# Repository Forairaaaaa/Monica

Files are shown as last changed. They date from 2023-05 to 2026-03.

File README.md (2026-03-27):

# Monica

视频介绍：https://www.bilibili.com/video/BV1AP411Q7dk

硬件开源：https://oshwhub.com/eda_rgprdhwej/monica

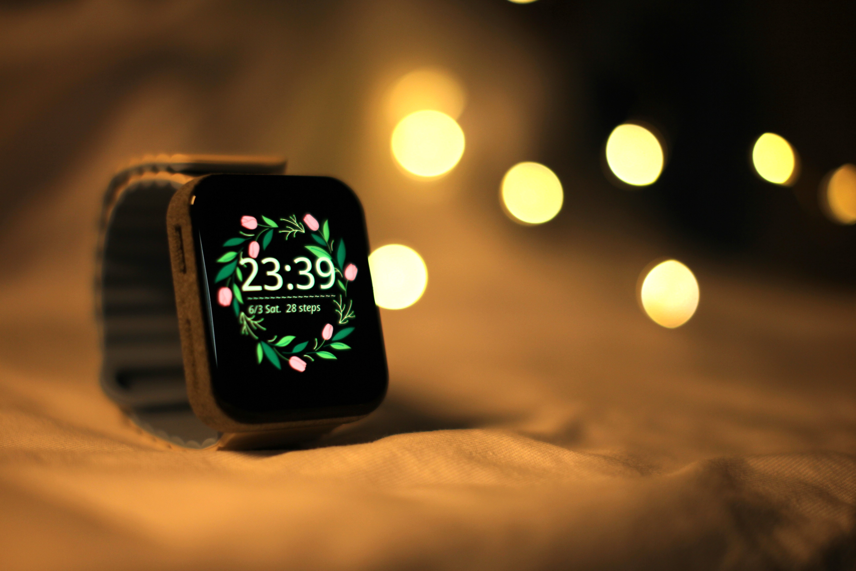
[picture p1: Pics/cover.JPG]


### 原理图

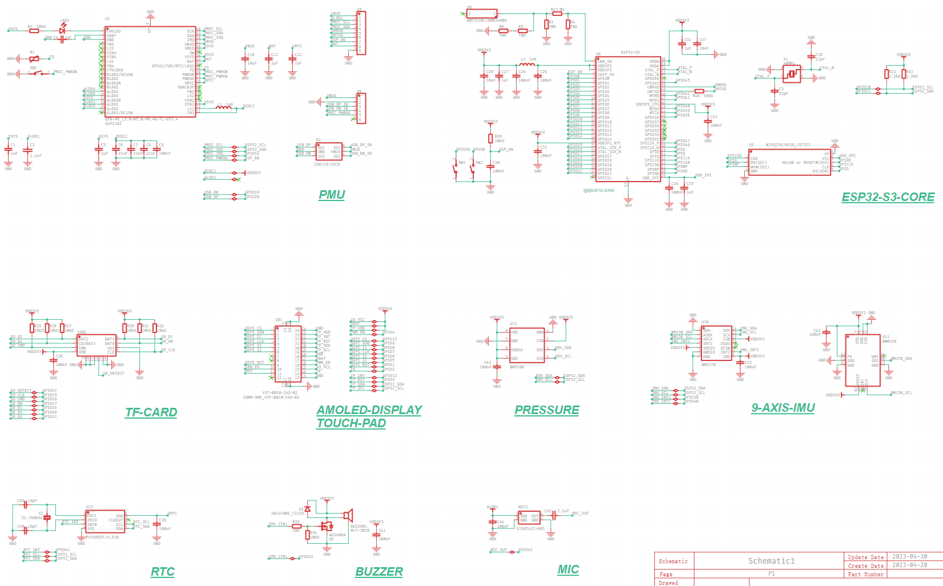
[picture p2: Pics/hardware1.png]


- **主控**：ESP32-S3，32M 外置 Flash
- **IMU**：BMI270 + BM150 （抬手唤醒、计步器、指南针）
- **电源管理**：AXP2101
- **其他**：SD卡槽、RTC、蜂鸣器、MIC、气压传感、按键
- [**屏幕**](https://item.taobao.com/item.htm?spm=a1z09.2.0.0.a41c2e8dNZ5GOq&id=688638221390)：1.8寸 Amoled 368*448 
- **[电池](https://detail.tmall.com/item.htm?_u=42bdtj0f19f8&id=632947661144)**：402728 400毫安

### PCB

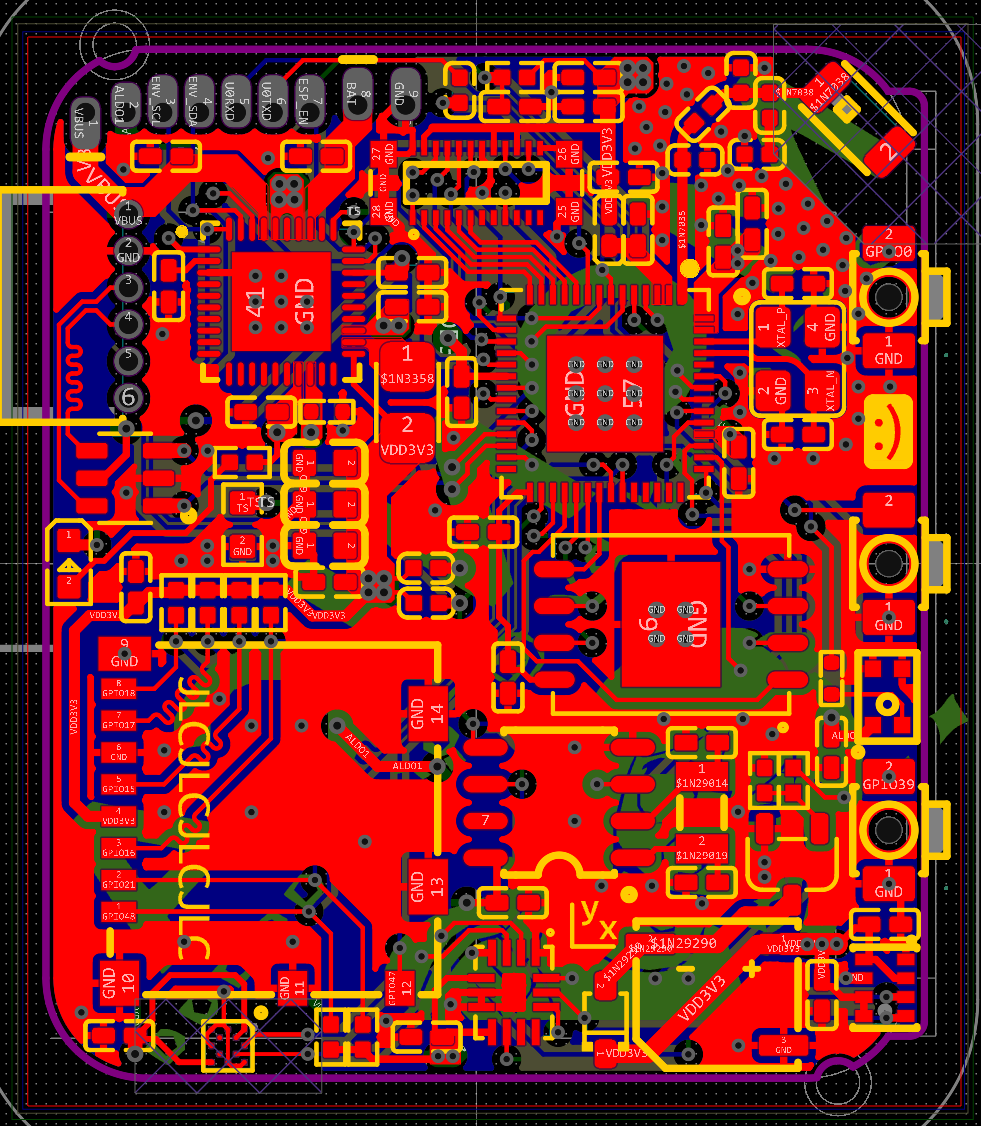
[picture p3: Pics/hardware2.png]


- 单面四层0.8MM，元件比较密集
- 1.27MM 母座用于下载和 USB 连接
- 引出串口和 I2C 接口等，预留用于底板拓展

### 程序

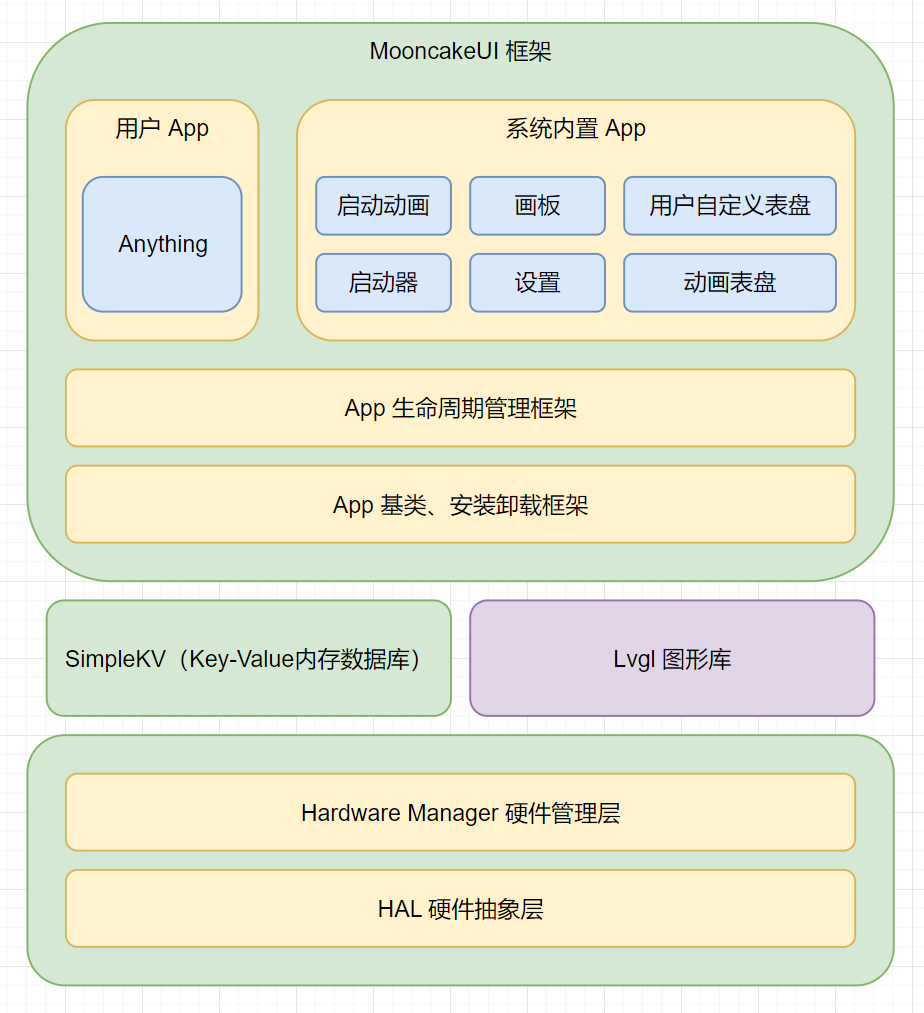
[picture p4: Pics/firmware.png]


#### 应用、驱动层解耦

- [**SimpleKV**](https://github.com/Forairaaaaa/simplekv.git)：简单的 `Key-Value (键-值)` 内存数据库框架，实现两层的数据交互。使用 `键` (字符串) 索引数据，切断应用层和驱动层的数据耦合。 
- [**Lvgl**](https://github.com/lvgl/lvgl.git)： 使用 Lvgl 作上层应用默认图形库，及其文件系统接口

因此，只要设备适配 Lvgl ，就可以直接使用这套 [Mooncake](https://github.com/Forairaaaaa/mooncake.git) UI框架，如 Linux ：

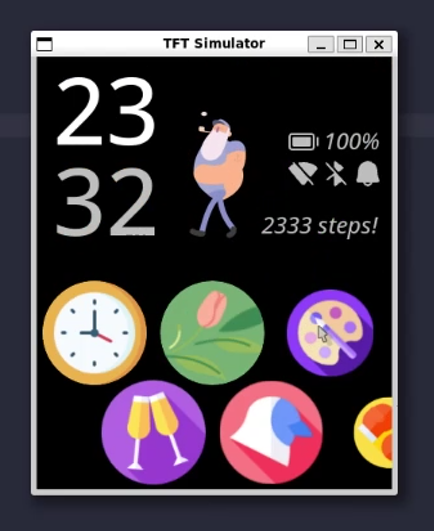
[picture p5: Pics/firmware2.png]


#### 驱动层

- **HAL**：外设驱动的对象抽象
- **Hardware Manager**：硬件管理层。负责底层的 `硬件初始化`、运行时的 `状态维护更新`，例如自动睡眠、抬手唤醒、计步器更新等
- **USB MSC 模式**：为了读写 SD 卡方便，同时按 `电源` 和 `下` 按键启动时，会进入 `USB MSC 模式`，SD 卡会被挂载成 U盘，接上 USB 即可直接读写

#### 应用层

- **App 基类、安装卸载**框架：所有 App 的对象基类，描述了 App 的基础框架。安装卸载框架实现简单的 App 列表管理

- **App 生命周期管理**：支持前后台的 App 运行生命周期 `调度器` (单线程，单前台，多后台) ，使用 `状态机` (FSM)实现

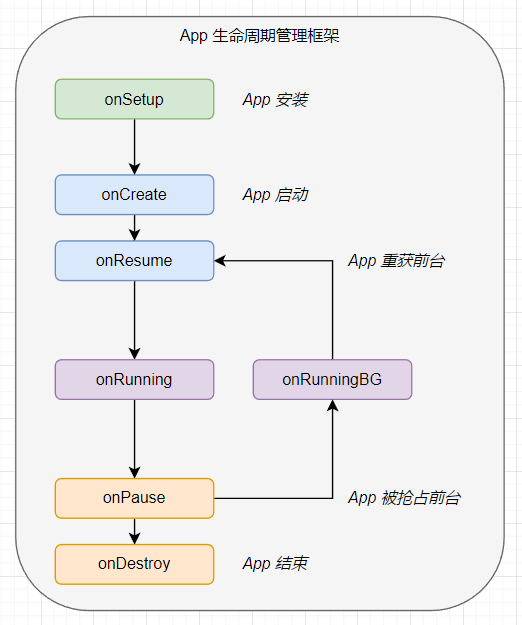
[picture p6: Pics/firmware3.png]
  

- **系统内置 APP**：都是在 App 层之上实现的应用，但 `启动动画` 和 `启动器` 会被 `Framwaork` 框架特殊调用

#### 用户自定义表盘

**watch_faces** 目录下的每一个文件夹都视作一个`表盘`

- **background** 目录：存放表盘背景资源 (png、gif)
- **number** 目录：存放从0~9的时间数字资源  (png)
- **face.json** ：资源描述文件，如时间数字坐标等

```shell
watch_faces/
|
├── AyanamiRei
│   ├── background
│   │   ├── background.png
│   ├── face.json
│   └── number
│       ├── 0.png
│       ├── ~
│       └── 9.png
|
├── FloatingNum
│   ├── background
│   │   └── background.png
│   ├── face.json
│   └── number
│       ├── 0.png
│       ├── ~
│       └── 9.png
|
└── PixelThinking
  ├── background
  │   ├── background.png
  ├── face.json
  └── number
      ├── 0.png
      ├── ~
      └── 9.png
```

### 模型

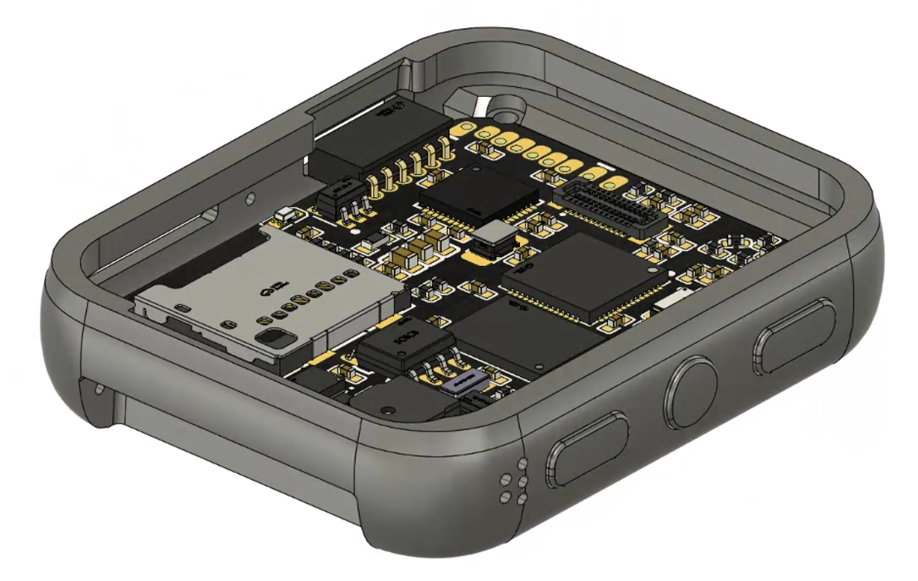
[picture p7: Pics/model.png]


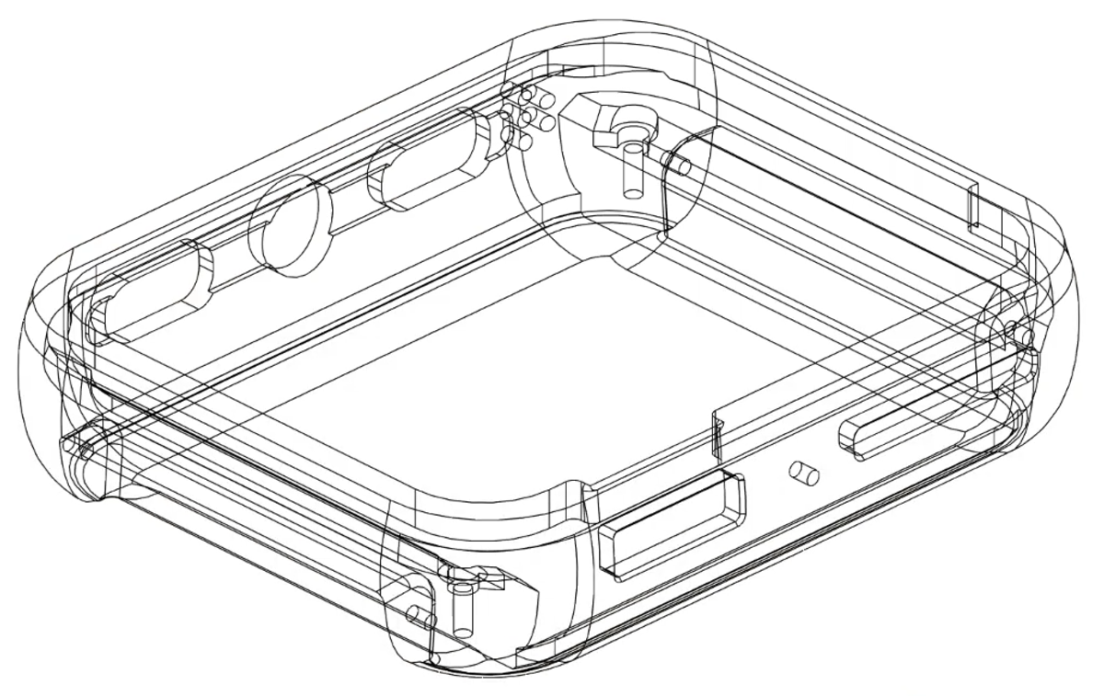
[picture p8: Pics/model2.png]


存在问题：

- 目前模型只能选激光烧结，树脂打印会有缝
- 按键位置有偏移，需要按靠上部位

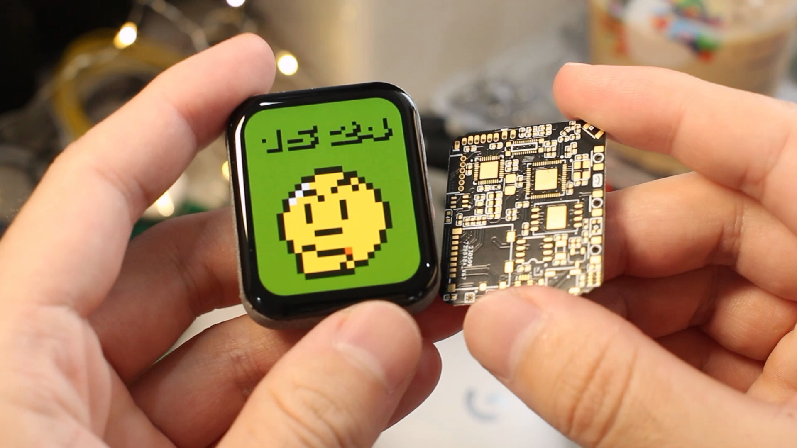
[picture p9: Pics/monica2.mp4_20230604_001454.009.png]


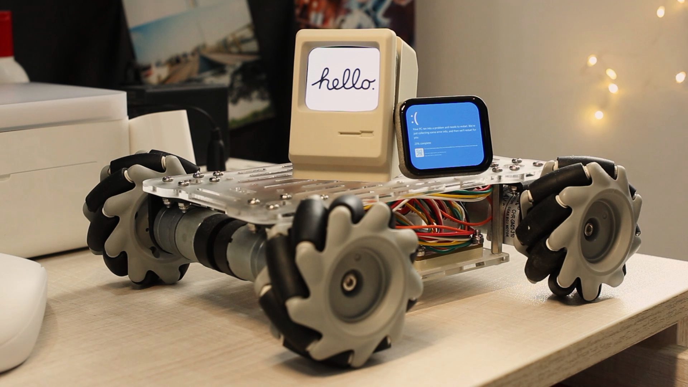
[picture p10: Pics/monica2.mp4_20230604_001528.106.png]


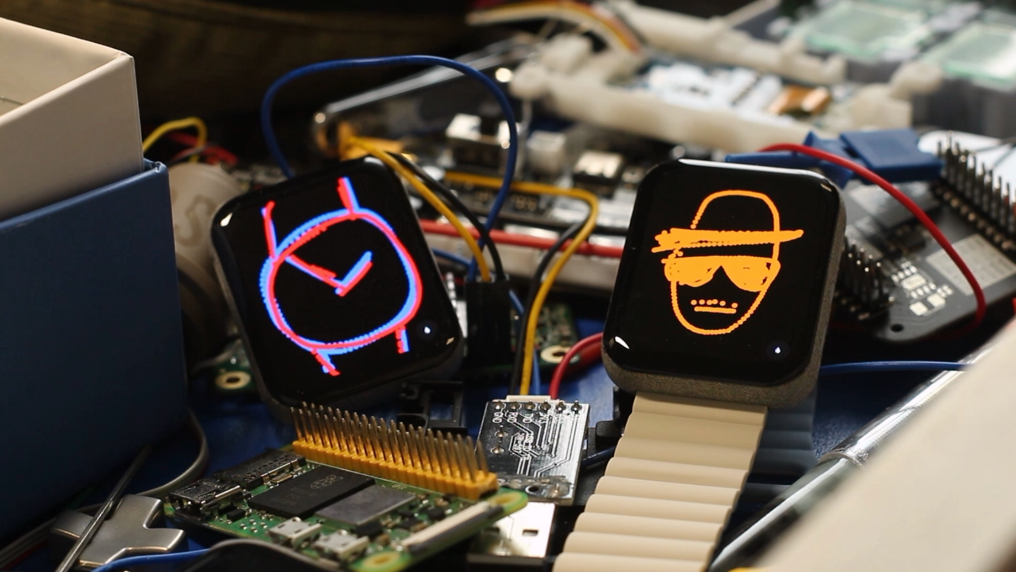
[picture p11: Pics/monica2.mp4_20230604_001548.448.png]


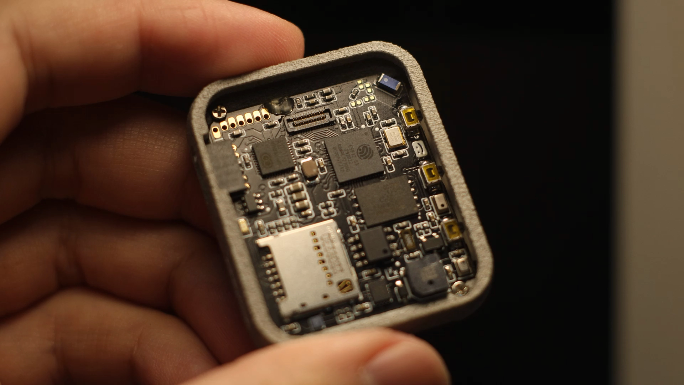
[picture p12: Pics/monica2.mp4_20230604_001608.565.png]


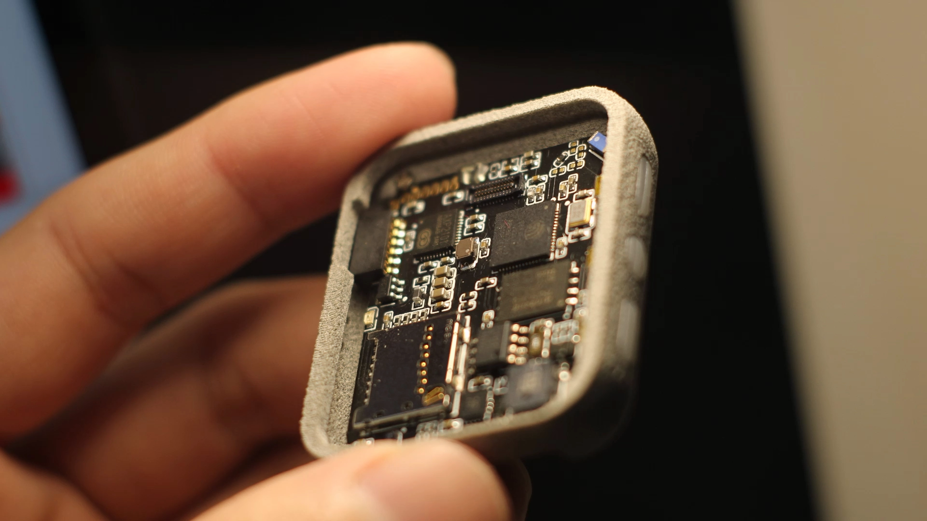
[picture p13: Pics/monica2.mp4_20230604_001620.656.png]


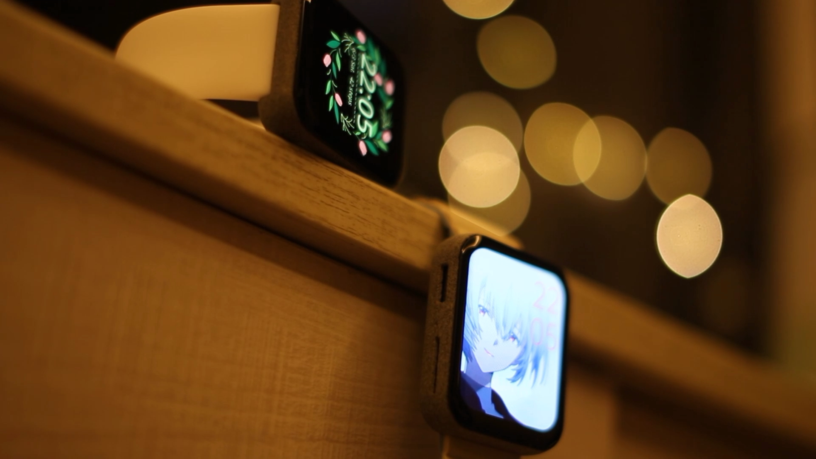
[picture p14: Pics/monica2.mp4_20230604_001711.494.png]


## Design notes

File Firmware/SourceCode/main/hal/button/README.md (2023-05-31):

Button
======

* Author: Michael Adams (<http://www.michael.net.nz>)
* Copyright (C) 2016 Michael D K Adams.
* Released under the MIT license.

Button is a tiny library to make reading buttons very simple. It handles debouncing automatically, and monitoring of state.

Motivation
----------
Ahh buttons. Ahh debouncing! Sometimes you really wish you could ignore all the mechanics of debouncing, reading inputs, monitoring state, and just say... `if (button.pressed())` and know that it'll only run once each time you press a button.

Or how about `if (button.released())`, or `button.toggled()`. It is such a simple concept, but in practice you need to set up timers, monitor input puts, set pullups, etc etc. On anything more than the most simple example, that can become quite a headache.

So fed up with all that I figured there had to be a better way. This library is the result.

Features
--------
* Super simple API.
* Handles debouncing.
* Sets the pin mode automatically.
* Lets you write code that triggers:
** based on the pin state (high or low)
** when a button is pressed
** when a button is released
** or when a button changes (i.e. pressing or releasing)

Requirements
------------
* An Arduino — http://arduino.cc/
* A button

Installation
------------
Download the ZIP archive (https://github.com/madleech/Button/zipball/master), then open the Arduino IDE and choose Sketch > Include Library > Add .ZIP Library... and select your downloaded file.

You should now see in File > Examples > Button entires for the basic\_usage example.

Code Examples
-------------
Here is the 'basic\_usage' example program, included in the download:

```C++
#include <Button.h>

Button button1(2); // Connect your button between pin 2 and GND
Button button2(3); // Connect your button between pin 3 and GND
Button button3(4); // Connect your button between pin 4 and GND

void setup() {
    button1.begin();
    button2.begin();
    button3.begin();

    while (!Serial) { }; // for Leos
    Serial.begin(9600);
}

void loop() {
    if (button1.pressed())
        Serial.println("Button 1 pressed");

    if (button2.released())
        Serial.println("Button 2 released");

    if (button3.toggled()) {
        if (button3.read() == Button::PRESSED)
            Serial.println("Button 3 has been pressed");
        else
            Serial.println("Button 3 has been released");
    }
}
```

Documentation
-------------
**Button(int pin)**
Creates a new Button.

**void begin()**
Call this in your `setup` method to setup the button. All it does is set the correct pin mode.

**bool pressed()**
Returns true when _and only when_ the button is pressed. Until the button is released (in the debounced-sense of the word) this function won't return true again. So in effect, it returns true only while you are pressing the button, or to put it another way, it fires on a rising edge.

**bool released()**
Like `pressed()`, but round the other way. So if you hold down a button, and then release it... that is when it fires.

**bool toggled()**
Returns true whenever the button is pressed or released, i.e., its position is toggled. To find out what the position actually is, you can use the `read()` function.

**bool read()**
Returns the current debounced state of the button, i.e. Button::PRESSED or Button::RELEASED.

**bool has_changed()**
Returns whether the position/state of the button has changed after calling the previous read() function. Unlikely to be used except by Super Gurus.

Quirks and Things to Keep in Mind
---------------------------------
**Highs and lows, lows and highs**
The easiest way to connect a switch on an Arduino is to connect it between an input pin and ground, and use the internal pullup resistor to make sure it doesn't float. This is fine and dandy, but it can get a bit confusing, as a "pressed" button is logic level: low, while a "released" button is logic level: high.

So to make it a bit more obvious what you're talking about, you can use a couple of handy shortcuts: `Button::PRESSED` and `Button::RELEASED` which map to the expected values.

License
-------
Copyright (c) 2016 Michael D K Adams. http://www.michael.net.nz/

Permission is hereby granted, free of charge, to any person obtaining a copy of this software and associated documentation files (the "Software"), to deal in the Software without restriction, including without limitation the rights to use, copy, modify, merge, publish, distribute, sublicense, and/or sell copies of the Software, and to permit persons to whom the Software is furnished to do so, subject to the following conditions:

The above copyright notice and this permission notice shall be included in all copies or substantial portions of the Software.

THE SOFTWARE IS PROVIDED "AS IS", WITHOUT WARRANTY OF ANY KIND, EXPRESS OR IMPLIED, INCLUDING BUT NOT LIMITED TO THE WARRANTIES OF MERCHANTABILITY, FITNESS FOR A PARTICULAR PURPOSE AND NONINFRINGEMENT. IN NO EVENT SHALL THE AUTHORS OR COPYRIGHT HOLDERS BE LIABLE FOR ANY CLAIM, DAMAGES OR OTHER LIABILITY, WHETHER IN AN ACTION OF CONTRACT, TORT OR OTHERWISE, ARISING FROM, OUT OF OR IN CONNECTION WITH THE SOFTWARE OR THE USE OR OTHER DEALINGS IN THE SOFTWARE.

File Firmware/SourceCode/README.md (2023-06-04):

#### 工具链：ESP-IDF v5.0.2

1. 更新依赖

   ```
   git submodule init
   git submodule update
   
   cd components/mooncake/
   git checkout main
   ```

2. 编译

   ```
   idf.py build
   ```

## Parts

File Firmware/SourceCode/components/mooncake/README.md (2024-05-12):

# Mooncake

基于 Lvgl 的 App 框架

App framework designed for DIY smart watch

Lvgl 模拟器(记得切换分支):

https://github.com/Forairaaaaa/lv_port_pc_eclipse/tree/mooncake_v8

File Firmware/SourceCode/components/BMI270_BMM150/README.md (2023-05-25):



`Arduino_BMI270_BMM150`
=======================





Allows you to read the accelerometer, magnetometer and gyroscope values from the combo BMI270+BMM150 IMU on your Arduino Nano 33 BLE Sense Rev2.

## :mag_right: Resources

* [How to install a library](https://www.arduino.cc/en/guide/libraries)
* [Help Center](https://support.arduino.cc/)
* [Forum](https://forum.arduino.cc)

## :bug: Bugs & Issues

If you want to report an issue with this library, you can submit it to the [issue tracker](https://github.com/arduino-libraries/Arduino_Braccio_plusplus/issues) of this repository. Remember to include as much detail as you can about your hardware set-up, code and steps for reproducing the issue. Make sure you're using an original Arduino board.

## :technologist: Development

There are many ways to contribute:

* Improve documentation and examples
* Fix a bug
* Test open Pull Requests
* Implement a new feature
* Discuss potential ways to improve this library

You can submit your patches directly to this repository as Pull Requests. Please provide a detailed description of the problem you're trying to solve and make sure you test on real hardware.

## :yellow_heart: Donations

This open-source code is maintained by Arduino with the help of the community. We invest a considerable amount of time in testing code, optimizing it and introducing new features. Please consider [donating](https://www.arduino.cc/en/donate/) or [sponsoring](https://github.com/sponsors/arduino) to support our work, as well as [buying original Arduino boards](https://store.arduino.cc/) which is the best way to make sure our effort can continue in the long term.

## License

Copyright (c) 2022 Arduino SA. All rights reserved.

This library is free software; you can redistribute it and/or
modify it under the terms of the GNU Lesser General Public
License as published by the Free Software Foundation; either
version 2.1 of the License, or (at your option) any later version.

This library is distributed in the hope that it will be useful,
but WITHOUT ANY WARRANTY; without even the implied warranty of
MERCHANTABILITY or FITNESS FOR A PARTICULAR PURPOSE. See the GNU
Lesser General Public License for more details.

You should have received a copy of the GNU Lesser General Public
License along with this library; if not, write to the Free Software
Foundation, Inc., 51 Franklin St, Fifth Floor, Boston, MA 02110-1301 USA

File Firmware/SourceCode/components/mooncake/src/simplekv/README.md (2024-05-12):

# SimpleKV
Simple Key-Value database (in memory so far)

#### Usage

```cpp
#include <simplekv.h>

SIMPLEKV::SimpleKV db;
```

#### Basic type

```cpp
db.Add<int>("Age", 666);
printf("Age: %d\n", db.Get("Age")->value<int>());
// > Age: 666

db.Put<int>("Age", -777);
printf("Age: %d\n", db.Get("Age")->value<int>());
// > Age: -777

db.Add<float>("float", 6.666);
db.Add<double>("double", 2333.3333333333);

printf("%f\n", db.Get("float")->value<float>());
// > 6.666000
printf("%.10f\n", db.Get("double")->value<double>());
// > 2333.3333333333
```

#### Array

```cpp
uint16_t data[10] = {0, 3, 6, 9, 12, 15, 18, 21, 24, 27};
db.Add("Data", data);

for (int i = 0; i < 10; i++) {
    printf("%d ", db.Get("Data")->value<uint16_t*>()[i]);
}
printf("\n");
// > 0 3 6 9 12 15 18 21 24 27
```

#### Custom type

```cpp
struct MyType_t {
    int a;
    float b;
    std::string status;
};
MyType_t my_type_1 = {11, 1.11, "nihao"};
MyType_t my_type_2 = {-22, -2.22, "wohao"};
MyType_t my_type_temp = {0};

db.Add("MyType_1", (void*)&my_type_1, sizeof(MyType_t));
db.Add("MyType_2", (void*)&my_type_2, sizeof(MyType_t));

my_type_temp = db.Get("MyType_1")->value<MyType_t>();
printf("%d %.2f %s\n", my_type_temp.a, my_type_temp.b, my_type_temp.status.c_str());
// > 11 1.11 nihao

my_type_temp = db.Get("MyType_2")->value<MyType_t>();
printf("%d %.2f %s\n", my_type_temp.a, my_type_temp.b, my_type_temp.status.c_str());
// > -22 -2.22 wohao
```

```cpp
/* << Bug >>: Add like this causes string become the same, don't know why */
db.Add("MyType_3", my_type_1);
db.Add("MyType_4", my_type_2);

my_type_temp = db.Get("MyType_3")->value<MyType_t>();
printf("%d %.2f %s\n", my_type_temp.a, my_type_temp.b, my_type_temp.status.c_str());
// > 11 1.11 wohao

my_type_temp = db.Get("MyType_4")->value<MyType_t>();
printf("%d %.2f %s\n", my_type_temp.a, my_type_temp.b, my_type_temp.status.c_str());
// > -22 -2.22 wohao
```

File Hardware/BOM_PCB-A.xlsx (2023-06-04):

No. | Quantity | Comment | Designator | Footprint | Value | Manufacturer Part | Manufacturer | Supplier Part | Supplier
1 | 1 | 4000Hz | BUZZER1 | BUZ-SMD_L5.0-W5.5-P4.60 | 4000Hz | MLT-5020 | 华能 | C94598 | LCSC
2 | 8 | 1uF | C1,C4,C5,C11,C12,C27,C32,C35 | C0402 | 1uF | CL05A105KA5NQNC | SAMSUNG(三星) | C52923 | LCSC
3 | 2 | 2.2uF | C2,C45 | C0402 | 2.2uF | CL05A225MQ5NSNC | SAMSUNG(三星) | C12530 | LCSC
4 | 2 | 22pF | C3,C18 | C0402 | 22pF | 0402CG220J500NT | FH(风华) | C1555 | LCSC
5 | 3 | 22uF | C6,C7,C8 | C0603 | 22uF | CL10A226MQ8NRNC | SAMSUNG(三星) | C59461 | LCSC
6 | 14 | 100nF | C9,C13,C28,C29,C30,C31,C33,C34,C36,C38,C41,C42,C43,C44 | C0402 | 100nF | CL05B104KO5NNNC | SAMSUNG(三星) | C1525 | LCSC
7 | 2 | 10uF | C10,C26 | C0402 | 10uF | CL05A106MQ5NUNC | SAMSUNG(三星) | C15525 | LCSC
8 | 1 | 10nF | C37 | C0402 | 10nF | CL05B103KB5NNNC | SAMSUNG(三星) | C15195 | LCSC
9 | 2 | 18pF | C39,C40 | C0402 | 18pF | 0402CG180J500NT | FH(风华) | C1549 | LCSC
10 | 1 | YXT-BB10-24S-02 | CN1 | CONN-SMD_YXT-BB10-24S-02 |  | YXT-BB10-24S-02 | YXT(益鑫通） | C2763965 | LCSC
11 | 1 | USBLC6-2SC6 | D1 | SOT-23-6_L2.9-W1.6-P0.95-LS2.8-BL |  | USBLC6-2SC6 | TECH PUBLIC(台舟) | C2827654 | LCSC
12 | 1 | 1N4148WS | D3 | SOD-323_L1.8-W1.3-LS2.5-RD |  | 1N4148WS | CJ(江苏长电/长晶) | C2128 | LCSC
13 | 1 | 1uH | L1 | IND-SMD_L2.5-W2.0_WPN252012H | 1uH | WPN252012H1R0MT | Sunlord(顺络) | C98348 | LCSC
14 | 1 | 2nH | L3 | L0402 | 2nH | LQG15HS2N0S02D | muRata(村田) | C18216 | LCSC
15 | 1 | 19-213/Y2C-CQ2R2L/3T(CY) | LED1 | LED0603-RD-YELLOW |  | 19-213/Y2C-CQ2R2L/3T(CY) | EVERLIGHT(亿光) | C72038 | LCSC
16 | 1 | S15OT421-005 | MIC1 | MIC-SMD_4P-L2.8-W1.9_S15OT421-005 |  | S15OT421-005 | Goertek(歌尔) | C2684419 | LCSC
17 | 1 | AO3400A | Q3 | SOT-23-3_L2.9-W1.6-P1.90-LS2.8-BR |  | AO3400A | AOS | C20917 | LCSC
18 | 1 | NCP18XH103F03RB | R1 | R0603 |  | NCP18XH103F03RB | muRata(村田) | C13564 | LCSC
19 | 9 | 10kΩ | R2,R26,R27,R28,R29,R30,R31,R32,R34 | R0402 | 10kΩ | 0402WGF1002TCE | UNI-ROYAL(厚声) | C25744 | LCSC
20 | 4 | TBD | R3,R4,R5,R6 | R0402 | TBD | 0402WGF0000TCE | UNI-ROYAL(厚声) | C17168 | LCSC
21 | 2 | 2.2kΩ | R22,R33 | R0402 | 2.2kΩ | 0402WGF2201TCE | UNI-ROYAL(厚声) | C25879 | LCSC
22 | 1 | 0Ω | R23 | R0402 | 0Ω | 0402WGF0000TCE | UNI-ROYAL(厚声) | C17168 | LCSC
23 | 1 | 499Ω | R24 | R0402 | 499Ω | RC0402FR-07499RL | YAGEO(国巨) | C137970 | LCSC
24 | 1 | 10Ω | R35 | R0402 | 10Ω | 0402WGF100JTCE | UNI-ROYAL(厚声) | C25077 | LCSC
25 | 1 | 1040310811 | SIM1 | SIM-SMD_8P-1040310811 |  | 1040310811 | MOLEX | C585350 | LCSC
26 | 3 | TS-1063S-B3D4 | SW1,SW2,SW3 | KEY-SMD_L3.0-W2.5-LS4.0_TS-1603S |  | TS-1063S-B3D4 | Yuandi(元迪) | C498291 | LCSC
27 | 1 | AXP2101 | U1 | QFN-40_L5.0-W5.0-P0.40-TL-EP3.4 |  | AXP2101 | Allwinner(全志) | C3036461 | LCSC
28 | 1 | X1311FR-06-C43D24 | U4 | HDR-TH_6P-P1.27-H-F-W4.5-N |  | X1311FR-06-C43D24 | XKB Connectivity(中国星坤) | C2881477 | LCSC
29 | 1 | X1311FR-09-C43D24 | U5 | HDR-TH_9P-P1.27-H-F-W4.5-N |  | X1311FR-09-C43D24 | XKB Connectivity(中国星坤) | C2881480 | LCSC
30 | 1 | ESP32-S3 | U6 | QFN-56_L7.0-W7.0-P0.40-TL-EP4.0 |  | ESP32-S3 | ESPRESSIF 乐鑫 | C2913192 | LCSC
31 | 1 | ANT3216LL00R2400A | U8 | ANT-SMD_L3.2-W1.6 |  | ANT3216LL00R2400A | YAGEO(国巨) | C293767 | LCSC
32 | 1 | W25Q256JVEIQ | U9 | WSON-8_L8.0-W6.10-P1.27-BL-EP |  | W25Q256JVEIQ | WINBOND(华邦) | C97522 | LCSC
33 | 1 | BMI270 | U10 | LGA-14_L3.0-W2.5-P0.50-BR |  | BMI270 | Bosch(博世) | C2836813 | LCSC
34 | 1 | BMM150 | U11 | WLCSP-12_L1.6-W1.6_BMM150 |  | BMM150 | Bosch(博世) | C171681 | LCSC
35 | 1 | BMP280 | U12 | WLGA-8_L2.5-W2.0-P0.65-TR_DPS422 |  | BMP280 | Bosch(博世) | C83291 | LCSC
36 | 1 | PCF8563T/5,518 | U13 | SOIC-8_L5.0-W4.0-P1.27-LS6.0-BL |  | PCF8563T/5,518 | NXP(恩智浦) | C7440 | LCSC
37 | 1 | 40MHz | X1 | OSC-SMD_4P-L3.2-W2.5-BL_SIT8008BI | 40MHz | X322540MPB4SI | YXC(扬兴晶振) | C9010 | LCSC
38 | 1 | 32.768kHz | X2 | FC-135R_L3.2-W1.5 | 32.768kHz | Q13FC1350000400 | EPSON(爱普生) | C32346 | LCSC

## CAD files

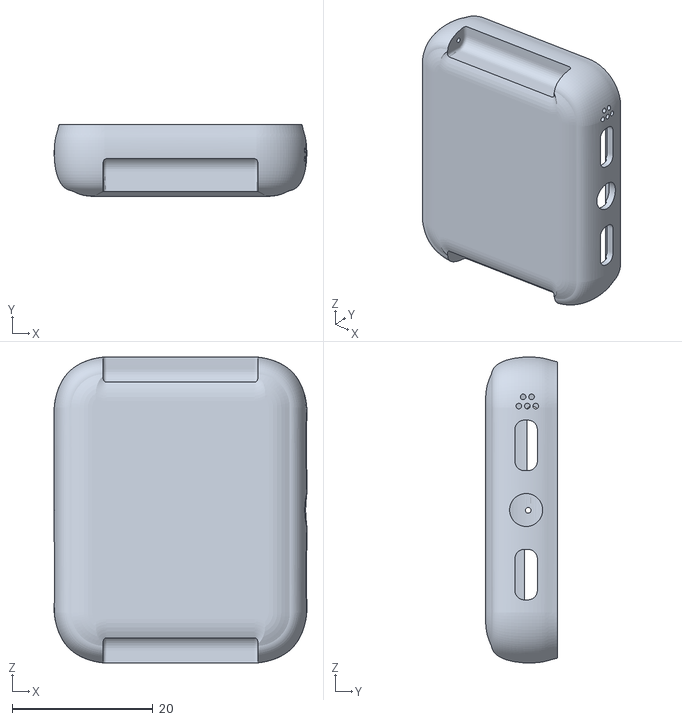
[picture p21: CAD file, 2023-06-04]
Model/Case.stl
36.0 x 10.2 x 43.6

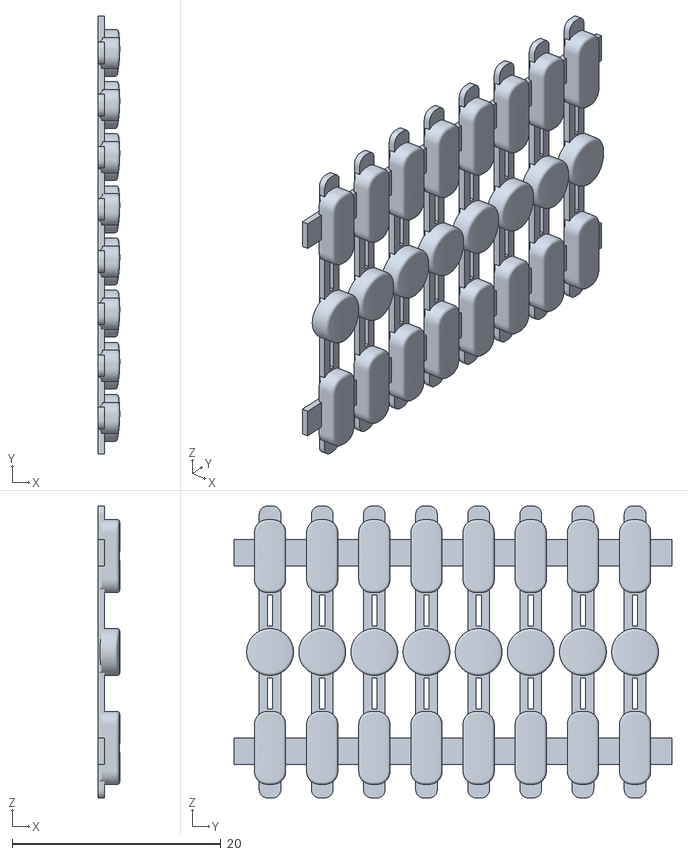
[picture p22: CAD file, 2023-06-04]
Model/kays.stl
2.07 x 42.0 x 28.0

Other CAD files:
Model/Case.f3d
Model/Keys.f3d

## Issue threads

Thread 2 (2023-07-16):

PSRAM报错

wagshiwei, 2023-07-16:
PSRAM报错，是bom表里的esp32 s3的型号写错了吧，s3是得带PSRAM吧。

Forairaaaaa, 2023-07-16:
是的，立创里没有那个型号，没有改

wagshiwei, 2023-07-16:
那是用的哪个型号啊 ESP32-S3R2   还是 ESP32-S3R8

Forairaaaaa, 2023-07-17:
> 那是用的哪个型号啊 ESP32-S3R2 还是 ESP32-S3R8 还是 ESP32-S3FH4R2 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

R8

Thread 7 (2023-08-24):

触摸驱动问题，INT引脚低电平不稳定

junxi-haoyi, 2023-08-24:
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

junxi-haoyi, 2023-08-24:
将上述代码修改一下，触摸正常，不知道是否是其他原因

Forairaaaaa, 2023-08-24:
这么神奇嘛，不过我暂时没屏幕了

junxi-haoyi, 2023-08-24:
触摸本身是有反应的，但是INT引脚低电平不稳定，导致LVGL触摸交互有问题，比如左滑，右滑屏幕没反应。

caoshengdong, 2024-01-31:
> 触摸本身是有反应的，但是INT引脚低电平不稳定，导致LVGL触摸交互有问题，比如左滑，右滑屏幕没反应。

我也发现了这个问题，请问能否提供完整代码？

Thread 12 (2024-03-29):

gif 图片播放卡顿

Huwensong, 2024-03-29:
你好，我们同样使用esp32s3 + lvgl gif 库播放动画，但是动画卡顿，远没有在monica 项目中播放的 gif 动画流畅，可以分享一下monica项目中的 background.gif 文件资源嘛。

Forairaaaaa, 2024-03-29:
[这个](https://github.com/Forairaaaaa/lv_port_pc_eclipse/tree/mooncake_v8/bin/sdcard/boot_anim)？

Huwensong, 2024-04-01:
我们是看到这个：
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
花环的动画播放很流畅，请问这个花环的动画效果是gif图嘛。
如果是，可以分享一下嘛，还是说是别的动画效果。

Forairaaaaa, 2024-04-01:
> 我们是看到这个： ![花环](https://private-user-images.githubusercontent.com/76541850/318316172-b60c6a18-bd5b-4d5e-a5cc-6c43622caa0e.jpg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) 花环的动画播放很流畅，请问这个花环的动画效果是gif图嘛。 如果是，可以分享一下嘛，还是说是别的动画效果。

不是

Huwensong, 2024-04-01:
是什么样的动画效果呢，mjpeg？

Forairaaaaa, 2024-04-01:
> 是什么样的动画效果呢，mjpeg？

rgb逐帧推

Huwensong, 2024-04-02:
ok,非常感谢

Forairaaaaa, 2024-04-02:
> ok,非常感谢

不客气

Closed 2024-04-02.

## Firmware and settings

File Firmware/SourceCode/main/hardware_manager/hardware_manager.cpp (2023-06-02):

/**
 * @file hardware_manager.cpp
 * @author Forairaaaaa
 * @brief 
 * @version 0.1
 * @date 2023-05-22
 * 
 * @copyright Copyright (c) 2023
 * 
 */
#include "hardware_manager.h"
#include "../hal/hal_config.h"
#include <esp_log.h>
#include <esp_sleep.h>


#define delay(ms) vTaskDelay(pdMS_TO_TICKS(ms))


namespace HM {


    static const char* TAG = "HM";


    void Hardware_Manager::_update_rtc_time()
    {
        /* If time just set */
        if (*_rtc_data.time_just_set_ptr) {
            
            /* Reset flag */
            *_rtc_data.time_just_set_ptr = false;

            /* Write into RTC data buffer */
            _rtc_data.rtc_time.tm_hour = _rtc_data.time_ptr->hour;
            _rtc_data.rtc_time.tm_min = _rtc_data.time_ptr->min;
            _rtc_data.rtc_time.tm_sec = _rtc_data.time_ptr->sec;
            _rtc_data.rtc_time.tm_year = _rtc_data.time_ptr->year + 1900;
            _rtc_data.rtc_time.tm_mon = _rtc_data.time_ptr->mon;
            _rtc_data.rtc_time.tm_mday = _rtc_data.time_ptr->mday;
            _rtc_data.rtc_time.tm_wday = _rtc_data.time_ptr->wday;

            /* Set RTC time */
            rtc.setTime(_rtc_data.rtc_time);

        }
        else {

            /* Read RTC */
            rtc.getTime(_rtc_data.rtc_time);
            // printf("%02d:%02d:%02d %d-%d-%d-%d\n",
            //     _rtc_data.rtc_time.tm_hour, _rtc_data.rtc_time.tm_min, _rtc_data.rtc_time.tm_sec,
            //     _rtc_data.rtc_time.tm_year, _rtc_data.rtc_time.tm_mon + 1, _rtc_data.rtc_time.tm_mday, _rtc_data.rtc_time.tm_wday);

            /* Write into database */
            _rtc_data.time_ptr->hour = _rtc_data.rtc_time.tm_hour;
            _rtc_data.time_ptr->min = _rtc_data.rtc_time.tm_min;
            _rtc_data.time_ptr->sec = _rtc_data.rtc_time.tm_sec;
            _rtc_data.time_ptr->year = _rtc_data.rtc_time.tm_year - 1900;
            _rtc_data.time_ptr->mon = _rtc_data.rtc_time.tm_mon;
            _rtc_data.time_ptr->mday = _rtc_data.rtc_time.tm_mday;
            _rtc_data.time_ptr->wday = _rtc_data.rtc_time.tm_wday;

        }

        /* Update power infos also */
        _update_power_infos();
    }


    void Hardware_Manager::_update_imu_data()
    {
        /* Read IMU */
        *_imu_data.steps = imu.getSteps();
    }


    void Hardware_Manager::_update_power_infos()
    {
        *_power_infos.battery_level_ptr = pmu.batteryLevel();
        *_power_infos.battery_is_charging_ptr = pmu.isCharging();
    }


    void Hardware_Manager::_update_go_sleep()
    {
        /* Check lvgl inactive time */
        if (lv_disp_get_inactive_time(NULL) > _power_manager.auto_sleep_time) {
            _power_manager.power_mode = mode_sleeping;
        }
    
    }


    void Hardware_Manager::_update_power_mode()
    {
        if (_power_manager.power_mode == mode_sleeping) {
            
            ESP_LOGI(TAG, "going sleep...");

            /* Close display */
            disp.setBrightness(1);
            
            /* Setup wakeup pins */
            /* Key Up */
            gpio_reset_pin(GPIO_NUM_0);
            gpio_set_direction(GPIO_NUM_0, GPIO_MODE_INPUT);
            gpio_sleep_set_pull_mode(GPIO_NUM_0, GPIO_PULLUP_ONLY);
            gpio_wakeup_enable(GPIO_NUM_0, GPIO_INTR_LOW_LEVEL);
            /* Touch pad */
            gpio_reset_pin(GPIO_NUM_12);
            gpio_set_direction(GPIO_NUM_12, GPIO_MODE_INPUT);
            gpio_sleep_set_pull_mode(GPIO_NUM_12, GPIO_PULLUP_ONLY);
            gpio_wakeup_enable(GPIO_NUM_12, GPIO_INTR_LOW_LEVEL);
            /* IMU */
            gpio_reset_pin(GPIO_NUM_40);
            gpio_set_direction(GPIO_NUM_40, GPIO_MODE_INPUT);
            gpio_sleep_set_pull_mode(GPIO_NUM_40, GPIO_FLOATING);
            gpio_wakeup_enable(GPIO_NUM_40, GPIO_INTR_LOW_LEVEL);

            esp_sleep_enable_gpio_wakeup();

            /* Go to sleep :) */
            esp_light_sleep_start();

            /* ---------------------------------------------------------------- */

            /* Wake up o.O */
            _power_manager.power_mode = mode_normal;

            /* Update data at once */
            _update_rtc_time();
            _update_imu_data();
            /* Clear key pwr */
            pmu.isKeyPressed();

            /* Tell Mooncake */
            *_system_data.just_wake_up_ptr = true;

            /* Restart display */
            disp.init();
            disp.setBrightness(1);
            disp.setColorDepth(16);

            /* Reset lvgl inactive time */
            lv_disp_trig_activity(NULL);

            /* Update a little bit before display on */
            getMooncake()->update();
            // lv_timer_handler();
            // delay(LV_DISP_DEF_REFR_PERIOD + 1);
            // lv_timer_handler();

            /* Refresh full screen */
            lv_obj_invalidate(lv_scr_act());

            /* Display on */
            disp.setBrightness(200);
        }
    }
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

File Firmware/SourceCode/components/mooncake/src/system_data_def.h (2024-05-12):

/**
 * @file system_data_def.h
 * @author Forairaaaaa
 * @brief 
 * @version 0.1
 * @date 2023-05-09
 * 
 * @copyright Copyright (c) 2023
 * 
 * Use define to unify baisc data's key in database(SimpleKV)
 * Framework will add them into database while init
 * It won't if no define
 */
#pragma once
#include <stdint.h>



/* Navigation */
#if 1
#define MC_KEY_MENU             "_KEY_MENU"     // bool
#define MC_KEY_HOME             "_KEY_HOME"     // bool
#define MC_KEY_BACK             "_KEY_BACK"     // bool
#define MC_KEY_POWER            "_KEY_PWR"      // bool
#define MC_KEY_UP               "_KEY_UP"       // bool
#define MC_KEY_DOWN             "_KEY_DOWN"     // bool
#endif


/* Time */
#if 1
#define MC_TIME                 "_TIME"         // MOONCAKE::DataTime_t
namespace MOONCAKE {
    struct DataTime_t {
        uint8_t sec = 0;		/* Seconds.	[0-60] (1 leap second) */
        uint8_t min = 32;		/* Minutes.	[0-59] */
        uint8_t hour = 23;		/* Hours.	[0-23] */
        uint8_t mday = 4;		/* Day.		[1-31] */
        uint8_t mon = 6;		/* Month.	[0-11] */
        uint8_t wday = 0;		/* Day of week.	[0-6] */
        int year = 99;			/* Year	- 1900.  */
        long int gmtoff = 0;	/* Seconds east of UTC */
        bool wasSet = false;    /* Flag to set time*/
    };
}
#define MC_TIME_JSUT_SET        "_TIME_SET"     // bool
#endif


/* Hardware */
#if 1
/* Display */
#define MC_DISP_HOR             "_DIS_HOR"      // int16_t
#define MC_DISP_VER             "_DIS_VER"      // int16_t
#define MC_DISP_BRIGHTNESS      "_DIS_BRI"      // uint8_t


/* System tick */
#define MC_SYSTEM_TICKS         "_SYS_TICK"     // uint32_t


/* Power */
#define MC_BATTERY_LEVEL        "_BAT_LV"       // uint8_t
#define MC_BATTERY_IS_CHARGING  "_BAT_CHG"      // bool


/* Wireless */
#define MC_WIFI_IS_CONNECTED    "_WIFI_CN"      // bool
#define MC_BLE_IS_CONNECTED     "_BLE_CN"       // bool


/* Notification */
#define MC_NOTIFICATION_IS_ON   "_NOTE_ON"      // bool


/* Setps */
#define MC_STEPS                "_STEPS"        // uint32_t


/* Flag of just wake up from sleep */
#define MC_JUST_WAKEUP          "_WAKE_UP"      // bool

#endif

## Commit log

2023-05-20 adding hal
    [partitions.csv]
2023-05-20 add power
2023-05-20 change charge judgment
2023-05-22 adding power manager
2023-05-25 add imu
2023-05-27 better strcuture data update before display on
    [partitions.csv]
2023-05-31 add button
2023-06-01 change usb msc quit from restart to poweroff, fix pwr key pressed from sleeping hit ui when waking up
    [hal.cpp, hal_usb_msc.c, hardware_manager.cpp]
2023-07-12 add fusion360 project files
    [Case.f3d, Keys.f3d]
